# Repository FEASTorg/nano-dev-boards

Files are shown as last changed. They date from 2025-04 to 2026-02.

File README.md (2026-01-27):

# nano-dev-boards

Nano-format MCU development boards designed in KiCad.

## Status

The development status of various versions of the Arduino Nano V3.3 KiCAD project is indicated below:






| Project | Status | Description |
| --- | --- | --- |
| Nano Every |  | Nano format featuring ATmega4809 microcontroller. |
| Nano Original |  | A recreation of the beloved Arduino Nano V3.3. |
| Nano Shield |  | A breakout shield board for Nano-format development boards. |

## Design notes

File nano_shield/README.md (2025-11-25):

# nano_shield

References:

- https://wiki.dfrobot.com/Arduino_Nano_IO_Shield__SKU__DFR0012_
- https://raw.githubusercontent.com/Arduinolibrary/DFRobot_Nano_shield/master/Nano%20Expansion%20V1.1.pdf

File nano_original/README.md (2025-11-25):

# Nano Original V3.3

A recreation of the beloved Arduino Nano V3.3.

## Parts Dump

- https://www.digikey.ca/en/products/detail/ftdi-future-technology-devices-international-ltd/FT232RNL-REEL/16836345
- https://www.digikey.ca/en/products/detail/amphenol-cs-fci/10118193-0001LF/2785388

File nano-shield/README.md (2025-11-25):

# Nano-Shield

## parts dump

- electrolytic cap
  - https://www.digikey.ca/en/products/detail/panasonic-electronic-components/EEE-HC1E470XP/672769
- smd pwr diode
  - https://www.digikey.ca/en/products/detail/smc-diode-solutions/1N4007FL/11657817
- smd slide dpdt switch
  - https://www.digikey.ca/en/products/detail/c-k/JS202011JCQN/6137630
- barrel jack pwr
  - https://www.digikey.ca/en/products/detail/same-sky-formerly-cui-devices/PJ-002AH/408446

## References

https://wiki.dfrobot.com/Arduino_Nano_IO_Shield__SKU__DFR0012_

https://raw.githubusercontent.com/Arduinolibrary/DFRobot_Nano_shield/master/Nano%20Expansion%20V1.1.pdf

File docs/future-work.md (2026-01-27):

# Future Work

## Board Variants & References

- **Nano 328PB variant**
  - [skumlos/atmega328pb-nano](https://github.com/skumlos/atmega328pb-nano)
  - [mspeculatrix/ATMEGA328PB_proto](https://github.com/mspeculatrix/ATMEGA328PB_proto)
  - [0x6470/ATmega328PB-Arduino-Nano-Clone-with-Bootloader](https://github.com/0x6470/ATmega328PB-Arduino-Nano-Clone-with-Bootloader)

- **Nano Every**
  - [ATMEGA4809-MU on Digi-Key](https://www.digikey.ca/en/products/detail/microchip-technology/ATMEGA4809-MU/10444906)
  - [ATSAMD11D14A-MUT on Digi-Key](https://www.digikey.ca/en/products/detail/microchip-technology/ATSAMD11D14A-MUT/5226471)

- **ST32 NUCLEO32**
  - [mkulesh/stm32DevelopmentBoards](https://github.com/mkulesh/stm32DevelopmentBoards)

- **DFRobot Nano v4.1 Clone**
  - [DFRobot Nano v4.1 Product Page](https://www.dfrobot.com/product-786.html)

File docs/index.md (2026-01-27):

# nano-dev-boards

nano-dev-boards is an open-source collection of nano-format MCU development boards and kits, designed in KiCad for streamlined embedded development, testing, and prototyping.

## References

- [Designing Arduino Nano Hardware](https://docs.arduino.cc/learn/hardware/nano-pcb-guide/)

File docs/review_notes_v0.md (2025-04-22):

# Review Notes v0

2025-04-21

## Schematic

- ERC clear

## Board

- DRC 2 errors
  - USB mini B doesnt match expected SMT vs THT: this is due to being mixed; its okay.
  - Thermal relief incomplete on MCU: this pin has copper pour one side and trace to gnd pad other side; many gnds; its okay.

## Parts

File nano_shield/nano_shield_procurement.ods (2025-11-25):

Reference | Value | Footprint | Datasheet | Qty | Cost | Total | Link
A1 | Arduino_Nano_v3.x | Module:Arduino_Nano | http://www.mouser.com/pdfdocs/Gravitech_Arduino_Nano3_0.pdf | 1 | 0 | 0 | N/A
C1,C2,C4,C5,C6,C7,C8 | 0.1u | Capacitor_SMD:C_0805_2012Metric_Pad1.18x1.45mm_HandSolder | ~ | 7 | 0.23 | 1.61 | https://www.digikey.ca/en/products/detail/murata-electronics/GCJ21BR72A104KA01L/2786665
C3 | 47u 25V | Capacitor_SMD:CP_Elec_6.3x7.7 | ~ | 1 | 0.62 | 0.62 | https://www.digikey.ca/en/products/detail/panasonic-electronic-components/EEE-HC1E470XP/672769
D1 | 1N4007 | Diode_SMD:D_SOD-123F | http://www.vishay.com/docs/88503/1n4001.pdf | 1 | 0.13 | 0.13 | https://www.digikey.ca/en/products/detail/smc-diode-solutions/1N4007FL/11657817
J1,J2,J3,J4,J8,J9,J10,J11,J14,J15,J16,J17,J27,J28,J31,J32,J35,J36 | Conn_01x04_Pin | Proto:PinHeader_1x04_P2.54mm_Vertical_TightCY | ~ | 18 | 0 | 0 | N/A
J5,J33 | Screw_Terminal_01x02 | TerminalBlock_4Ucon:TerminalBlock_4Ucon_1x02_P3.50mm_Horizontal | ~ | 2 | 0 | 0 | N/A
J6,J13,J19,J22,J23,J25,J26 | Conn_01x02_Pin | Proto:PinHeader_1x02_P2.54mm_Vertical_TightCY | ~ | 7 | 0 | 0 | N/A
J7 | Barrel_Jack_Switch | Connector_BarrelJack:BarrelJack_Horizontal | ~ | 1 | 0.64 | 0.64 | https://www.digikey.ca/en/products/detail/same-sky-formerly-cui-devices/PJ-002AH/408446
J12,J18,J20,J29 | Conn_01x08_Socket | Proto:PinSocket_1x08_P2.54mm_Vertical_TightCY | ~ | 4 | 0 | 0 | N/A
J21,J24,J30,J34 | Conn_01x05_Pin | Proto:PinHeader_1x05_P2.54mm_Vertical_TightCY | ~ | 4 | 0 | 0 | N/A
R1 | 1k | Resistor_SMD:R_0805_2012Metric_Pad1.20x1.40mm_HandSolder | ~ | 1 | 0.1 | 0.1 | https://www.digikey.ca/en/products/detail/vishay-dale/CRCW08051K00FKEA/1175637
R2 | 10k | Resistor_SMD:R_0805_2012Metric_Pad1.20x1.40mm_HandSolder | ~ | 1 | 0.1 | 0.1 | https://www.digikey.ca/en/products/detail/vishay-dale/CRCW080510K0FKEA/1175751
SW1,SW2 | SW_Slide_DPDT | Button_Switch_SMD:SW_DPDT_CK_JS202011JCQN | ~ | 2 | 0.84 | 1.68 | https://www.digikey.ca/en/products/detail/c-k/JS202011JCQN/6137630
 |  |  |  |  | TOTAL | 4.88

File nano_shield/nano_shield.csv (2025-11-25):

Reference | Value | Footprint | Datasheet | Qty | DNP | Exclude from BOM | Exclude from Board
A1 | Arduino_Nano_v3.x | Module:Arduino_Nano | http://www.mouser.com/pdfdocs/Gravitech_Arduino_Nano3_0.pdf | 1
C1,C2,C4,C5,C6,C7,C8 | 0.1u | Capacitor_SMD:C_0805_2012Metric_Pad1.18x1.45mm_HandSolder | ~ | 7
C3 | 47u 25V | Capacitor_SMD:CP_Elec_6.3x7.7 | ~ | 1
D1 | 1N4007 | Diode_SMD:D_SOD-123F | http://www.vishay.com/docs/88503/1n4001.pdf | 1
J1,J2,J3,J4,J8,J9,J10,J11,J14,J15,J16,J17,J27,J28,J31,J32,J35,J36 | Conn_01x04_Pin | Proto:PinHeader_1x04_P2.54mm_Vertical_TightCY | ~ | 18
J5,J33 | Screw_Terminal_01x02 | TerminalBlock_4Ucon:TerminalBlock_4Ucon_1x02_P3.50mm_Horizontal | ~ | 2
J6,J13,J19,J22,J23,J25,J26 | Conn_01x02_Pin | Proto:PinHeader_1x02_P2.54mm_Vertical_TightCY | ~ | 7
J7 | Barrel_Jack_Switch | Connector_BarrelJack:BarrelJack_Horizontal | ~ | 1
J12,J18,J20,J29 | Conn_01x08_Socket | Proto:PinSocket_1x08_P2.54mm_Vertical_TightCY | ~ | 4
J21,J24,J30,J34 | Conn_01x05_Pin | Proto:PinHeader_1x05_P2.54mm_Vertical_TightCY | ~ | 4
R1 | 1k | Resistor_SMD:R_0805_2012Metric_Pad1.20x1.40mm_HandSolder | ~ | 1
R2 | 10k | Resistor_SMD:R_0805_2012Metric_Pad1.20x1.40mm_HandSolder | ~ | 1
SW1,SW2 | SW_Slide_DPDT | Button_Switch_SMD:SW_DPDT_CK_JS202011JCQN | ~ | 2

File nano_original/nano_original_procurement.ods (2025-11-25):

Reference | Value | Footprint | Datasheet | Description | Qty | Cost | Total | Link | Notes
C1,C4,C7 | 1u | Capacitor_SMD:C_0805_2012Metric_Pad1.18x1.45mm_HandSolder | ~ | Unpolarized capacitor | 3 | 0.16 | 0.48 | https://www.digikey.ca/en/products/detail/murata-electronics/GRM21BR71A105KA01L/586695 | GRM21BR71A105KA01L
C2,C6,C8,C9 | 100n | Capacitor_SMD:C_0805_2012Metric_Pad1.18x1.45mm_HandSolder | ~ | Unpolarized capacitor | 4 | 0.23 | 0.92 | https://www.digikey.ca/en/products/detail/murata-electronics/GCJ21BR72A104KA01L/2786665 | GCJ21BR72A104KA01L
C3,C5 | 4.7u | Capacitor_Tantalum_SMD:CP_EIA-3216-18_Kemet-A_HandSolder | https://www.mouser.ca/datasheet/2/447/KEM_T2050_T491_AUTO-3316838.pdf | Polarized capacitor | 2 | 0.85 | 1.7 | https://www.mouser.ca/ProductDetail/KEMET/T491A475K016ATAUTO?qs=WOKUqv%2F%2FT%2FajmXGoWOX%252BHg%3D%3D
D1 | LED_Green_POW | LED_SMD:LED_0805_2012Metric_Pad1.15x1.40mm_HandSolder | ~ | Light emitting diode | 1 | 0.15 | 0.15 | https://www.digikey.ca/en/products/detail/liteon/LTST-C171GKT/386793
D2 | SS1P3L | Diode_SMD:D_SMP_DO-220AA | https://www.vishay.com/docs/88915/ss1p3l.pdf | Diode | 1 | 0.46 | 0.46 | https://www.digikey.ca/en/products/detail/vishay-general-semiconductor-diodes-division/SS1P3L-M3-84A/1091542
D3 | LED_Red_RX | LED_SMD:LED_0805_2012Metric_Pad1.15x1.40mm_HandSolder | ~ | Light emitting diode | 1 | 0.15 | 0.15 | https://www.digikey.ca/en/products/detail/liteon/LTST-C171KRKT/386801
D4 | LED_Green_TX | LED_SMD:LED_0805_2012Metric_Pad1.15x1.40mm_HandSolder | ~ | Light emitting diode | 1 | 0.15 | 0.15 | https://www.digikey.ca/en/products/detail/liteon/LTST-C171GKT/386793
D5 | LED_Orange_ONB | LED_SMD:LED_0805_2012Metric_Pad1.15x1.40mm_HandSolder | ~ | Light emitting diode | 1 | 0.15 | 0.15 | https://www.digikey.ca/en/products/detail/liteon/LTST-C170KFKT/386775
F1 | PTC RESET FUSE | Fuse:Fuse_0603_1608Metric_Pad1.05x0.95mm_HandSolder | https://www.bourns.com/docs/product-datasheets/mf-fsmf.pdf | Resettable fuse, polymeric positive temperature coefficient, small symbol | 1 | 0.49 | 0.49 | https://www.digikey.ca/en/products/detail/bourns-inc/MF-FSMF050X-2/2039256
FID1,FID2,FID3,FIDe1 | Fiducial | Fiducial:Fiducial_0.75mm_Mask1.5mm | ~ | Fiducial Marker | 4 | 0 | 0 | -
J1 | USB_B_Micro | Connector_USB:USB_Micro-B_Amphenol_10118193-0001LF_Horizontal | ~ | USB Micro Type B connector | 1 | 0.41 | 0.41 | https://www.digikey.ca/en/products/detail/amphenol-cs-fci/10118193-0001LF/2785388
J2,J3 | Conn_01x15 | Connector_PinSocket_2.54mm:PinSocket_1x15_P2.54mm_Vertical | ~ | Generic connector, single row, 01x15, script generated (kicad-library-utils/schlib/autogen/connector/) | 2 | 0.2 | 0.4 | https://www.digikey.ca/en/products/detail/adam-tech/PH1-15-UA/9830359
J4 | Conn_02x03_Odd_Even | Connector_PinHeader_2.54mm:PinHeader_2x03_P2.54mm_Vertical | ~ | Generic connector, double row, 02x03, odd/even pin numbering scheme (row 1 odd numbers, row 2 even numbers), script generated (kicad-library-utils/schlib/autogen/connector/) | 1 | 0.24 | 0.24 | https://www.digikey.ca/en/products/detail/harwin-inc/M20-9980346/3728085
RN1,RN2 | 1k | Resistor_SMD:R_Cat16-4 | ~ | 4 resistor network, parallel topology, split | 2 | 0.1 | 0.2 | https://www.digikey.ca/en/products/detail/yageo/YC164-JR-071KL/1005123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
SW1 | SW_Push | Button_Switch_SMD:SW_SPST_B3U-1000P | ~ | Push button switch, generic, two pins | 1 | 0.98 | 0.98 | https://www.digikey.ca/en/products/detail/omron-electronics-inc-emc-div/B3U-1000P/1534338
TP1 | D+ | TestPoint:TestPoint_Pad_D1.0mm | ~ | test point | 1 | 0 | 0 | -
TP2 | D- | TestPoint:TestPoint_Pad_D1.0mm | ~ | test point | 1 | 0 | 0 | -
U1 | LM1117MP-5.0 | Package_TO_SOT_SMD:SOT-223-3_TabPin2 | http://www.ti.com/lit/ds/symlink/lm1117.pdf | 800mA Low-Dropout Linear Regulator, 5.0V fixed output, SOT-223 | 1 | 1.38 | 1.38 | https://www.digikey.ca/en/products/detail/texas-instruments/LM1117MP-5-0-NOPB/363590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
U2 | FT231XS | Package_SO:SSOP-20_3.9x8.7mm_P0.635mm | https://www.ftdichip.com/Support/Documents/DataSheets/ICs/DS_FT231X.pdf | Full Speed USB to Full Handshake UART, SSOP-20 | 1 | 2.34 | 2.34 | https://www.digikey.ca/en/products/detail/ftdi-future-technology-devices-international-ltd/FT231XS-U/3749471
U3 | ATmega328P-M | Package_DFN_QFN:QFN-32-1EP_5x5mm_P0.5mm_EP3.1x3.1mm | http://ww1.microchip.com/downloads/en/DeviceDoc/ATmega328_P%20AVR%20MCU%20with%20picoPower%20Technology%20Data%20Sheet%2040001984A.pdf | 20MHz, 32kB Flash, 2kB SRAM, 1kB EEPROM, QFN-32 | 1 | 2.74 | 2.74 | https://www.digikey.ca/en/products/detail/microchip-technology/ATMEGA328P-MUR/2357092
Y1 | 16MHz | Crystal:Resonator_SMD_Murata_CSTxExxV-3Pin_3.0x1.1mm | ~ | Three pin ceramic resonator | 1 | 0.35 | 0.35 | https://www.mouser.ca/ProductDetail/Murata-Electronics/CSTNE16M0V530000R0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 | CSTNE16M0V530000R0
 |  |  |  |  |  | TOTAL | 13.69

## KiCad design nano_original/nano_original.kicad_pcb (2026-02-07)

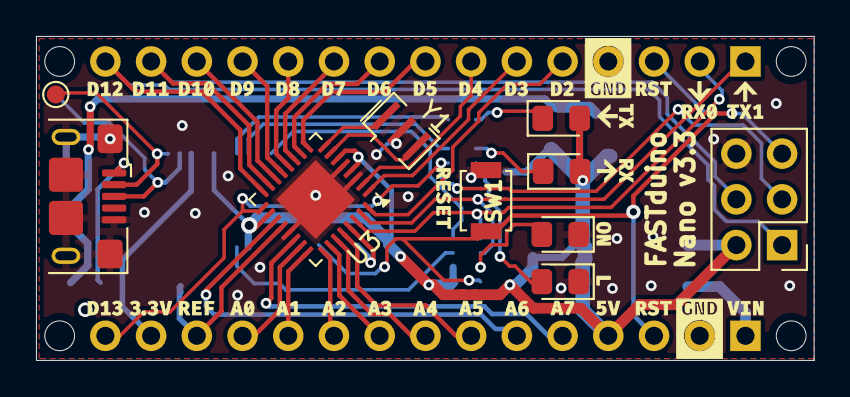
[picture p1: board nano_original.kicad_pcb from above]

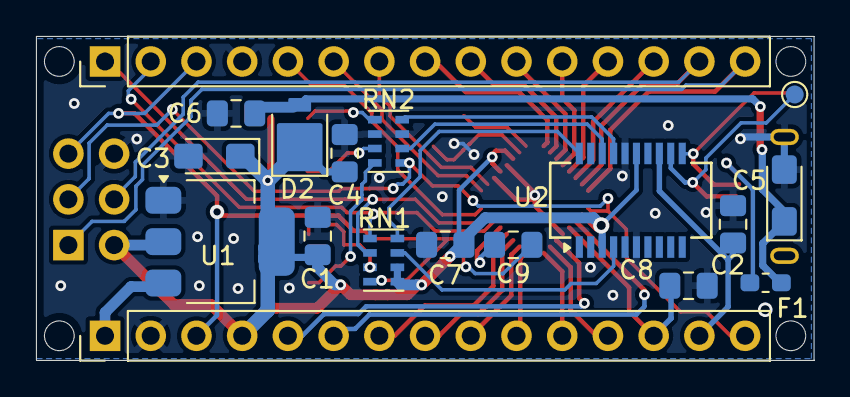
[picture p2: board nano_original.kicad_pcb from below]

Board: 2 copper layers, 43.2 x 18.0 mm, 29 parts (18 on the bottom side), 43 nets.

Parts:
C1, C4, C7: 1u; C_0805_2012Metric_Pad1.18x1.45mm_HandSolder
C2, C6, C8, C9: 100n; C_0805_2012Metric_Pad1.18x1.45mm_HandSolder
C3, C5: 4.7u; CP_EIA-3216-18_Kemet-A_HandSolder
D1: LED_Green_POW; LED_0805_2012Metric_Pad1.15x1.40mm_HandSolder
D2: SS1P3L; D_SMP_DO-220AA
D3: LED_Red_RX; LED_0805_2012Metric_Pad1.15x1.40mm_HandSolder
D4: LED_Green_TX; LED_0805_2012Metric_Pad1.15x1.40mm_HandSolder
D5: LED_Orange_ONB; LED_0805_2012Metric_Pad1.15x1.40mm_HandSolder
F1: PTC RESET FUSE; Fuse_0603_1608Metric_Pad1.05x0.95mm_HandSolder
J1: USB_B_Micro; USB_Micro-B_Amphenol_10118193-0001LF_Horizontal
J2, J3: Conn_01x15; PinHeader_1x15_P2.54mm_Vertical
J4: Conn_02x03_Odd_Even; PinHeader_2x03_P2.54mm_Vertical
RN1, RN2: 1k; R_Cat16-4
SW1: SW_Push; SW_SPST_B3U-1000P
Silkscreen_Front: Silkscreen_Back; Silkscreen_Front
TP1: D+; TestPoint_Pad_D1.0mm
TP2: D-; TestPoint_Pad_D1.0mm
U1: LM1117MP-5.0; SOT-223-3_TabPin2
U2: FT231XS; SSOP-20_3.9x8.7mm_P0.635mm
U3: ATmega328P-MUR; QFN-32-1EP_5x5mm_P0.5mm_EP3.1x3.1mm
Y1: 16MHz; Resonator_SMD_Murata_CSTxExxV-3Pin_3.0x1.1mm

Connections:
+3.3V: C2.1, J3.14, U2.13 (3V3OUT)
+5V: C1.1, C3.1, C4.1, C7.1, D2.1 (K), D3.2 (A), D4.2 (A), J3.4, J4.2, RN1.5 (R4.2), RN1.6 (R3.2), U1.2 (VO), U2.3 (VCCIO), U2.15 (VCC), U3.4 (VCC), U3.6 (VCC), U3.18 (AVCC)
/A0: J3.12, U3.23 (PC0)
/A1: J3.11, U3.24 (PC1)
/A2: J3.10, U3.25 (PC2)
/A3: J3.9, U3.26 (PC3)
/A4: J3.8, U3.27 (PC4)
/A5: J3.7, U3.28 (PC5)
/A6: J3.6, U3.19 (ADC6)
/A7: J3.5, U3.22 (ADC7)
/AREF: C8.1, J3.13, U3.20 (AREF)
/D0/RX: J2.2, RN1.1 (R1.1), U3.30 (PD0)
/D1/TX: J2.1, RN1.2 (R2.1), U3.31 (PD1)
/D2: J2.5, U3.32 (PD2)
/D3: J2.6, U3.1 (PD3)
/D4: J2.7, U3.2 (PD4)
/D5: J2.8, U3.9 (PD5)
/D6: J2.9, U3.10 (PD6)
/D7: J2.10, U3.11 (PD7)
/D8: J2.11, U3.12 (PB0)
/D9: J2.12, U3.13 (PB1)
/D10: J2.13, U3.14 (PB2)
/D11/MOSI: J2.14, J4.4, U3.15 (PB3)
/D12/MISO: J2.15, J4.1, U3.16 (PB4)
/D13/SCK: J3.15, J4.3, RN2.1 (R1.1), U3.17 (PB5)
/RESET: C9.2, J2.3, J3.3, J4.5, RN1.4 (R4.1), SW1.2
/RX: RN1.8 (R1.2), U2.20 (TXD)
/TX: RN1.7 (R2.2), U2.4 (RXD)
GND: C1.2, C2.2, C3.2, C4.2, C5.2, C6.2, C7.2, C8.2, D1.1 (K), D5.1 (K), J1.5 (GND), J1.6 (Shield), J2.4, J3.2, J4.6, RN2.3 (R3.1), RN2.6 (R3.2), SW1.1, U1.1 (GND), U2.6 (GND), U2.16 (GND), U3.3 (GND), U3.5 (GND), U3.21 (GND), U3.33 (GND), Y1.2
unnamed: D1.2 (A), RN1.3 (R3.1)
unnamed: D3.1 (K), RN2.7 (R2.2)
unnamed: D4.1 (K), RN2.5 (R4.2)
unnamed: D5.2 (A), RN2.8 (R1.2)
unnamed: J1.3 (D+), TP1.1, U2.12 (USBDM)
unnamed: J1.2 (D-), TP2.1, U2.11 (USBDP)
unnamed: F1.1, J1.1 (VBUS)
unnamed: RN2.2 (R2.1), U2.18 (CBUS0)
unnamed: RN2.4 (R4.1), U2.17 (CBUS1)
unnamed: U3.7 (XTAL1/PB6), Y1.3
unnamed: U3.8 (XTAL2/PB7), Y1.1
unnamed: C9.1, U3.29 (~RESET/PC6)
VIN: J3.1, U1.3 (VI)
VUSB: C5.1, C6.1, D2.2 (A), F1.2

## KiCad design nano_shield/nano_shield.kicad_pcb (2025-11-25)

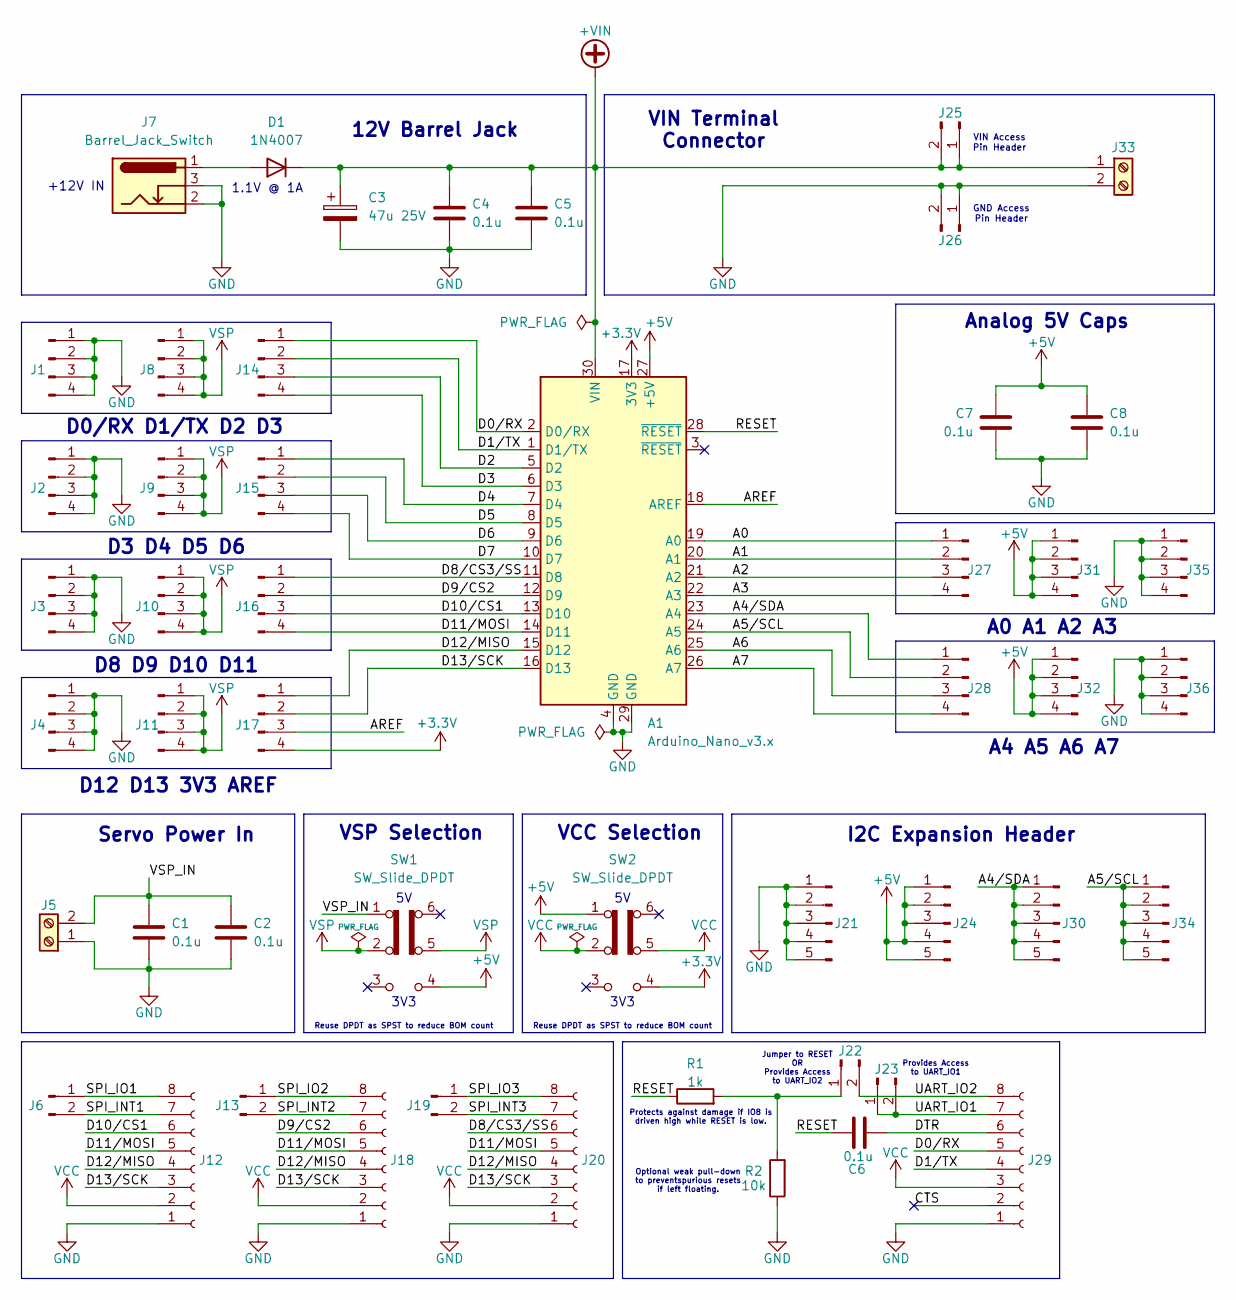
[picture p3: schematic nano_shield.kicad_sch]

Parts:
A1: Arduino_Nano_v3.x; Arduino_Nano
C1, C2, C4, C5, C6, C7, C8: 0.1u; C_0805_2012Metric_Pad1.18x1.45mm_HandSolder
C3: 47u 25V; CP_Elec_6.3x7.7
D1: 1N4007; D_SOD-123F
J1, J2, J3, J4, J8, J9, J10, J11, J14, J15, J16, J17, J27, J28, J31, J32, J35, J36: Conn_01x04_Pin; PinHeader_1x04_P2.54mm_Vertical_TightCY
J5, J33: Screw_Terminal_01x02; TerminalBlock_4Ucon_1x02_P3.50mm_Horizontal
J6, J13, J19, J22, J23, J25, J26: Conn_01x02_Pin; PinHeader_1x02_P2.54mm_Vertical_TightCY
J7: Barrel_Jack_Switch; BarrelJack_Horizontal
J12, J18, J20, J29: Conn_01x08_Socket; PinSocket_1x08_P2.54mm_Vertical_TightCY
J21, J24, J30, J34: Conn_01x05_Pin; PinHeader_1x05_P2.54mm_Vertical_TightCY
R1: 1k; R_0805_2012Metric_Pad1.20x1.40mm_HandSolder
R2: 10k; R_0805_2012Metric_Pad1.20x1.40mm_HandSolder
SW1, SW2: SW_Slide_DPDT; SW_DPDT_CK_JS202011JCQN

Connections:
+3.3V: A1.17 (3V3), J17.4, SW2.4 (A)
+5V: A1.27 (+5V), C7.1, C8.1, J24.1, J24.2, J24.3, J24.4, J24.5, J31.1, J31.2, J31.3, J31.4, J32.1, J32.2, J32.3, J32.4, SW1.4 (A), SW2.1 (A)
+VIN: A1.30 (VIN), C3.1, C4.1, C5.1, D1.1 (K), J25.1, J25.2, J33.1
/A0: A1.19 (A0), J27.1
/A1: A1.20 (A1), J27.2
/A2: A1.21 (A2), J27.3
/A3: A1.22 (A3), J27.4
/A4/SDA: A1.23 (A4), J28.1, J30.1, J30.2, J30.3, J30.4, J30.5
/A5/SCL: A1.24 (A5), J28.2, J34.1, J34.2, J34.3, J34.4, J34.5
/A6: A1.25 (A6), J28.3
/A7: A1.26 (A7), J28.4
/AREF: A1.18 (AREF), J17.3
/CTS: J29.2
/D0/RX: A1.2 (D0/RX), J14.1, J29.5
/D1/TX: A1.1 (D1/TX), J14.2, J29.4
/D2: A1.5 (D2), J14.3
/D3: A1.6 (D3), J14.4
/D4: A1.7 (D4), J15.1
/D5: A1.8 (D5), J15.2
/D6: A1.9 (D6), J15.3
/D7: A1.10 (D7), J15.4
/D8/CS3/SS: A1.11 (D8), J16.1, J20.6
/D9/CS2: A1.12 (D9), J16.2, J18.6
/D10/CS1: A1.13 (D10), J12.6, J16.3
/D11/MOSI: A1.14 (D11), J12.5, J16.4, J18.5, J20.5
/D12/MISO: A1.15 (D12), J12.4, J17.1, J18.4, J20.4
/D13/SCK: A1.16 (D13), J12.3, J17.2, J18.3, J20.3
/DTR: C6.2, J29.6
/RESET: A1.28 (~RESET), C6.1, R1.1
/SPI_INT1: J6.2, J12.7
/SPI_INT2: J13.2, J18.7
/SPI_INT3: J19.2, J20.7
/SPI_IO1: J6.1, J12.8
/SPI_IO2: J13.1, J18.8
/SPI_IO3: J19.1, J20.8
/UART_IO1: J23.1, J23.2, J29.7
/UART_IO2: J22.2, J29.8
/VSP_IN: C1.1, C2.1, J5.2, SW1.1 (A)
GND: A1.4 (GND), A1.29 (GND), C1.2, C2.2, C3.2, C4.2, C5.2, C7.2, C8.2, J1.1, J1.2, J1.3, J1.4, J2.1, J2.2, J2.3, J2.4, J3.1, J3.2, J3.3, J3.4, J4.1, J4.2, J4.3, J4.4, J5.1, J7.2, J7.3, J12.1, J18.1, J20.1, J21.1, J21.2, J21.3, J21.4, J21.5, J26.1, J26.2, J29.1, J33.2, J35.1, J35.2, J35.3, J35.4, J36.1, J36.2, J36.3, J36.4, R2.1
unnamed: D1.2 (A), J7.1
unnamed: J22.1, R1.2, R2.2
VCC: J12.2, J18.2, J20.2, J29.3, SW2.2 (B), SW2.5 (B)
VSP: J8.1, J8.2, J8.3, J8.4, J9.1, J9.2, J9.3, J9.4, J10.1, J10.2, J10.3, J10.4, J11.1, J11.2, J11.3, J11.4, SW1.2 (B), SW1.5 (B)

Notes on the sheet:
D0/RX D1/TX D2 D3
D8 D9 D10 D11
Analog 5V Caps
GND Access Pin Header
D3 D4 D5 D6
Jumper to RESET OR Provides Access to UART_IO2
1.1V @ 1A
+12V IN
VSP Selection
D12 D13 3V3 AREF
VIN Access Pin Header
3V3
Protects against damage if IO8 is driven high while RESET is low.
Reuse DPDT as SPST to reduce BOM count
A0 A1 A2 A3
Provides Access to UART_IO1
VCC Selection
A4 A5 A6 A7
Servo Power In
VIN Terminal Connector
Optional weak pull-down to preventspurious resets if left floating.
I2C Expansion Header
12V Barrel Jack

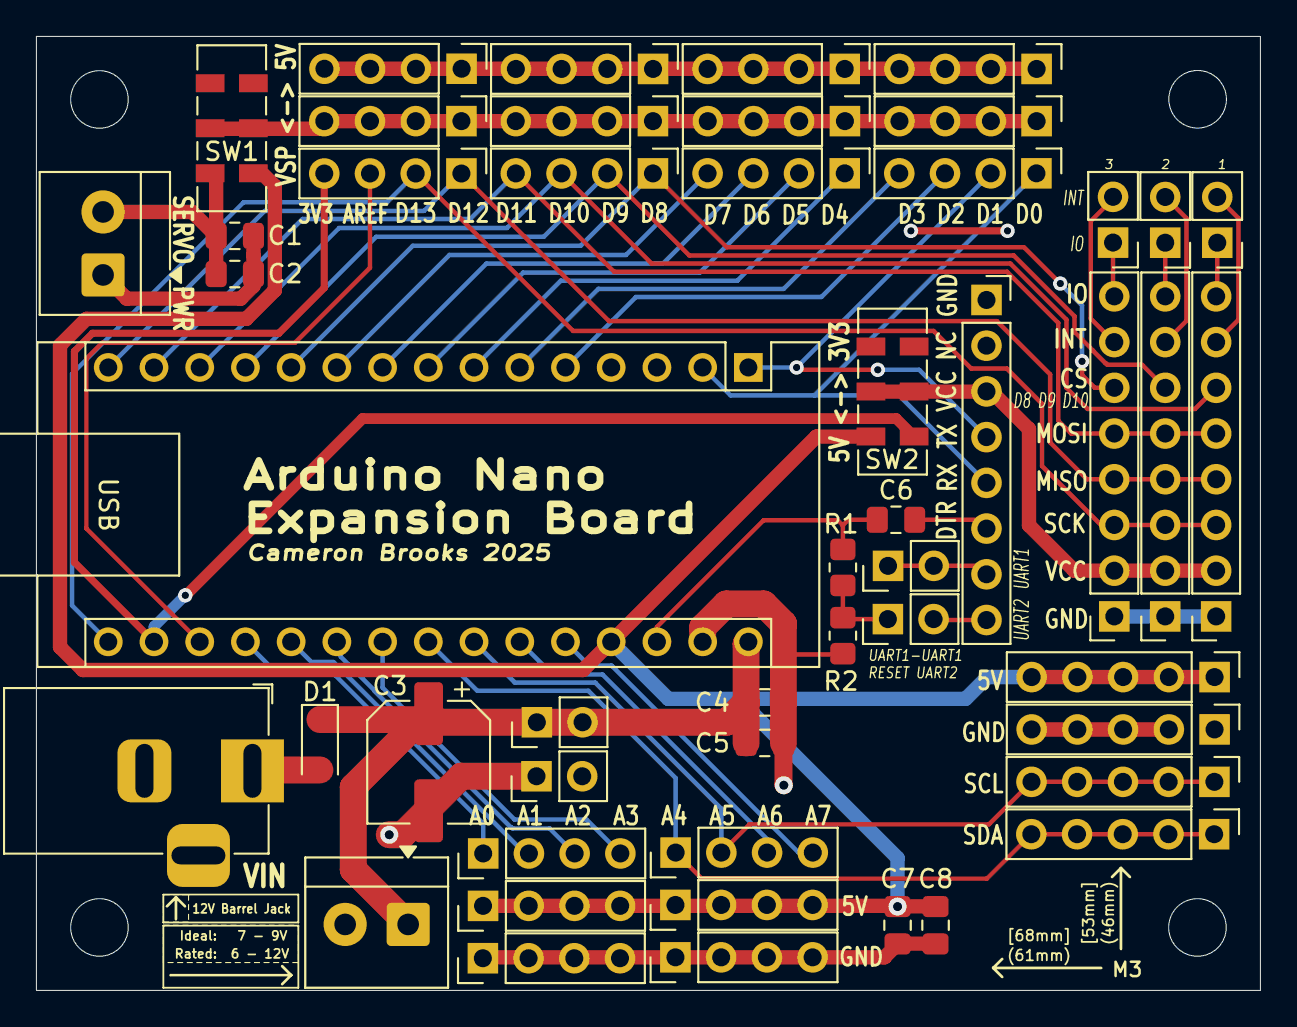
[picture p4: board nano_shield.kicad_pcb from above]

Board: 2 copper layers, 68.0 x 53.0 mm, 50 parts (0 on the bottom side), 42 nets.

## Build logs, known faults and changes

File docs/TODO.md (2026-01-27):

# TODO

- [ ] workflow to view boards (bread-infra; will need to make multi for this and protokit)

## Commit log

2025-04-21 added docs
    [nano_every.kicad_pcb, nano_every.kicad_sch, nano_original.kicad_pcb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]
2025-04-22 updated BOM
    [nano_original-B_Cu.gbr, nano_original-B_Mask.gbr, nano_original-B_Paste.gbr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]
2025-11-25 tranfer: nano shield from other repo
    [nano-shield-B_Cu.gbr, nano-shield-B_Mask.gbr, nano-shield-B_Silkscreen.gbr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]
2025-11-25 rename shield to use underscore
    [nano_shield-B_Cu.gbr, nano_shield-B_Mask.gbr, nano_shield-B_Silkscreen.gbr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]
2025-11-25 rename to remove v3
    [nano_original-B_Cu.gbr, nano_original-B_Mask.gbr, nano_original-B_Paste.gbr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]
2025-11-25 update procurement spreadsheets and clean backups
    [nano_original-B_Cu.gbr, nano_original-B_Mask.gbr, nano_original-B_Paste.gbr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]
2025-11-25 update procurement for shield
    [nano_shield_procurement.ods]
2026-02-07 critical fix: swap tx and rx between atmega328p and ft231 (smooth brain moment)
    [nano_original.kicad_pcb, nano_original.kicad_sch]
